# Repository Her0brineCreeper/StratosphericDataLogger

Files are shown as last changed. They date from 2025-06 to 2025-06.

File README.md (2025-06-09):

# StratosphericDataLogger
This repository contains the design and source code of the Stratospheric Data Logger developed by Bryan Hoxha during the European Project Semester 2025 at Politehnica Bucharest.
It was developed to log the measurements of a number of sensors onto a microSD card during a stratospheric balloon flight.
# Hardware
- ESP32 microcontroller (a FireBeetle 2 ESP32-E was used for this project)
- 2x BME280 for inside and outside the payload
- MS5611 pressure sensor (inside)
- SCD41 CO₂ sensor (inside)
- SI1145 light/UV sensor (outside)
- RCB-09T-01 GPS module (other GPS modules should work fine as well)
- SPI microSD card module
- custom-made PCB (made in KiCad v8) with modular design and two extra outputs (I²C) for additional sensors
- one of which was used for an MPU6050 accelerometer/gyroscope (inside)
# Software
- made in Arduino IDE
- logs sensor measurements to a CSV file and outputs them to Serial Monitor
- Sensors are hot pluggable during operation because their presence is checked during every measurement cycle.

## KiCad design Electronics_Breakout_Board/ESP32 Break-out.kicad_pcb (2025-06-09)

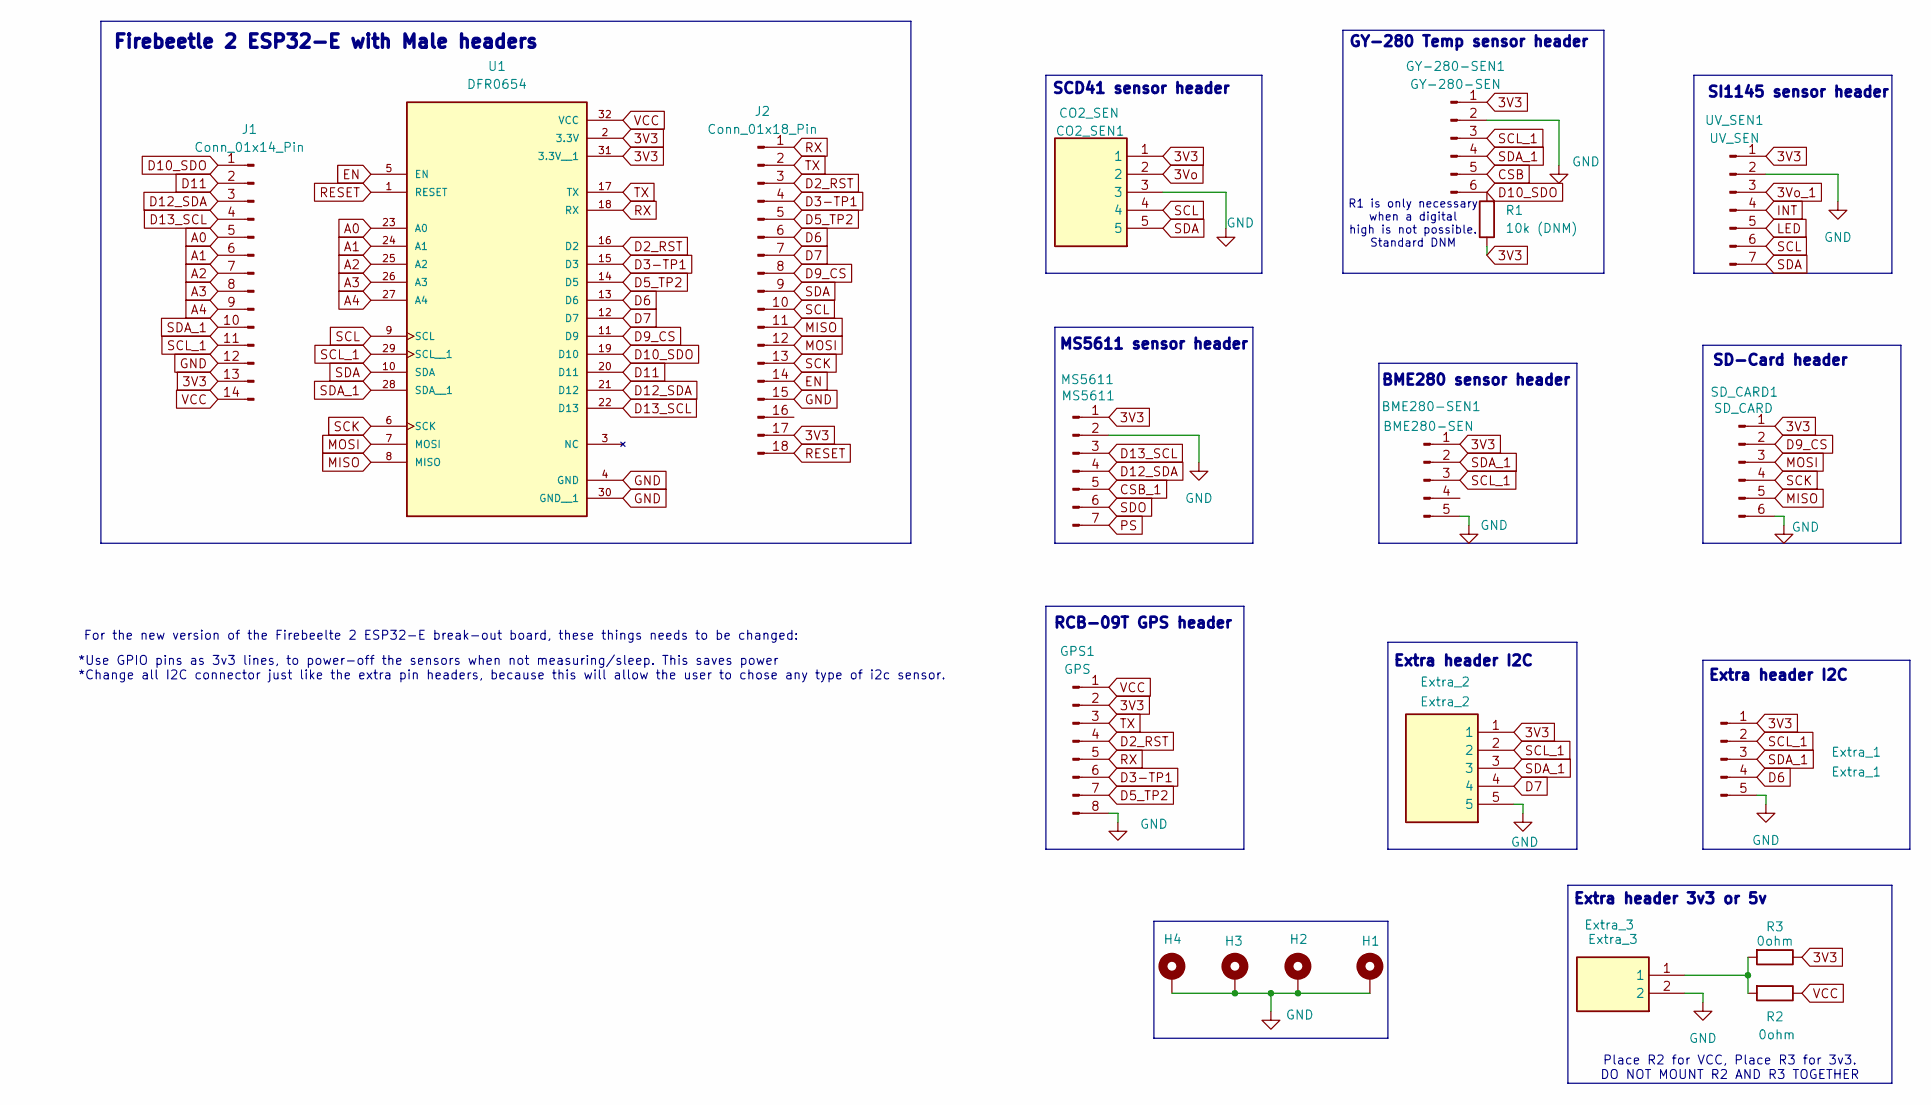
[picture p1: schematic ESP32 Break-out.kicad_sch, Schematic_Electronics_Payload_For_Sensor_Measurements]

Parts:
BME280-SEN1: BME280-SEN; 2200970571
CO2_SEN1: CO2_SEN; 2200970571; Manufacturer_Part_Number 220097-0571
Extra_1: Extra_1; 2200970571; Manufacturer_Part_Number 220097-0571
Extra_2: Extra_2; 2200970571; Manufacturer_Part_Number 220097-0571
Extra_3: Extra_3; 2200970271; Manufacturer_Part_Number 220097-0271; Mouser Part Number 538-220097-0271
GPS1: GPS; 2200970871
GY-280-SEN1: GY-280-SEN; 2200970671
H1, H2, H3, H4: MountingHole_Pad; MountingHole_2.2mm_M2_DIN965_Pad
J1: Conn_01x14_Pin; PinHeader_1x14_P2.54mm_Vertical
J2: Conn_01x18_Pin; PinHeader_1x18_P2.54mm_Vertical
MS5611: MS5611; CONN_2200970000-SD_07_MOL
R1: 10k (DNM); C_0805_2012Metric
R2, R3: 0ohm; C_0805_2012Metric
SD_CARD1: SD_CARD; 2200970671
U1: DFR0654; MODULE_DFR0654
UV_SEN1: UV_SEN; CONN_2200970000-SD_07_MOL

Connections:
3V3: BME280-SEN1.1, CO2_SEN1.1, Extra_1.1, Extra_2.1, GPS1.2, GY-280-SEN1.1, J1.13, J2.17, MS5611.1, R1.1, R3.1, SD_CARD1.1, U1.2 (3.3V), U1.31 (3.3V__1), UV_SEN1.1
3Vo: CO2_SEN1.2
3Vo_1: UV_SEN1.3
A0: J1.5, U1.23 (A0)
A1: J1.6, U1.24 (A1)
A2: J1.7, U1.25 (A2)
A3: J1.8, U1.26 (A3)
A4: J1.9, U1.27 (A4)
CSB: GY-280-SEN1.5
CSB_1: MS5611.5
D2_RST: GPS1.4, J2.3, U1.16 (D2)
D3-TP1: GPS1.6, J2.4, U1.15 (D3)
D5_TP2: GPS1.7, J2.5, U1.14 (D5)
D6: Extra_1.4, J2.6, U1.13 (D6)
D7: Extra_2.4, J2.7, U1.12 (D7)
D9_CS: J2.8, SD_CARD1.2, U1.11 (D9)
D10_SDO: GY-280-SEN1.6, J1.1, R1.2, U1.19 (D10)
D11: J1.2, U1.20 (D11)
D12_SDA: J1.3, MS5611.4, U1.21 (D12)
D13_SCL: J1.4, MS5611.3, U1.22 (D13)
EN: J2.14, U1.5 (EN)
GND: BME280-SEN1.5, CO2_SEN1.3, Extra_1.5, Extra_2.5, Extra_3.2, GPS1.8, GY-280-SEN1.2, H1.1, H2.1, H3.1, H4.1, J1.12, J2.15, MS5611.2, SD_CARD1.6, U1.4 (GND), U1.30 (GND__1), UV_SEN1.2
INT: UV_SEN1.4
LED: UV_SEN1.5
MISO: J2.11, SD_CARD1.5, U1.8 (MISO)
MOSI: J2.12, SD_CARD1.3, U1.7 (MOSI)
unnamed: Extra_3.1, R2.2, R3.2
PS: MS5611.7
RESET: J2.18, U1.1 (RESET)
RX: GPS1.5, J2.1, U1.18 (RX)
SCK: J2.13, SD_CARD1.4, U1.6 (SCK)
SCL: CO2_SEN1.4, J2.10, U1.9 (SCL), UV_SEN1.6
SCL_1: BME280-SEN1.3, Extra_1.2, Extra_2.2, GY-280-SEN1.3, J1.11, U1.29 (SCL__1)
SDA: CO2_SEN1.5, J2.9, U1.10 (SDA), UV_SEN1.7
SDA_1: BME280-SEN1.2, Extra_1.3, Extra_2.3, GY-280-SEN1.4, J1.10, U1.28 (SDA__1)
SDO: MS5611.6
TX: GPS1.3, J2.2, U1.17 (TX)
VCC: GPS1.1, J1.14, R2.1, U1.32 (VCC)

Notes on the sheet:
MS5611 sensor header
*Use GPIO pins as 3v3 lines, to power-off the sensors when not measuring/sleep. This saves power *Change all I2C connector just like the extra pin headers, because this will allow the user to chose any type of i2c sensor.
For the new version of the Firebeelte 2 ESP32-E break-out board, these things needs to be changed:
SCD41 sensor header
RCB-09T GPS header
SI1145 sensor header
GY-280 Temp sensor header
Extra header I2C
Firebeetle 2 ESP32-E with Male headers
BME280 sensor header
Extra header 3v3 or 5v
R1 is only necessary when a digital high is not possible. Standard DNM
SD-Card header
Place R2 for VCC, Place R3 for 3v3. DO NOT MOUNT R2 AND R3 TOGETHER

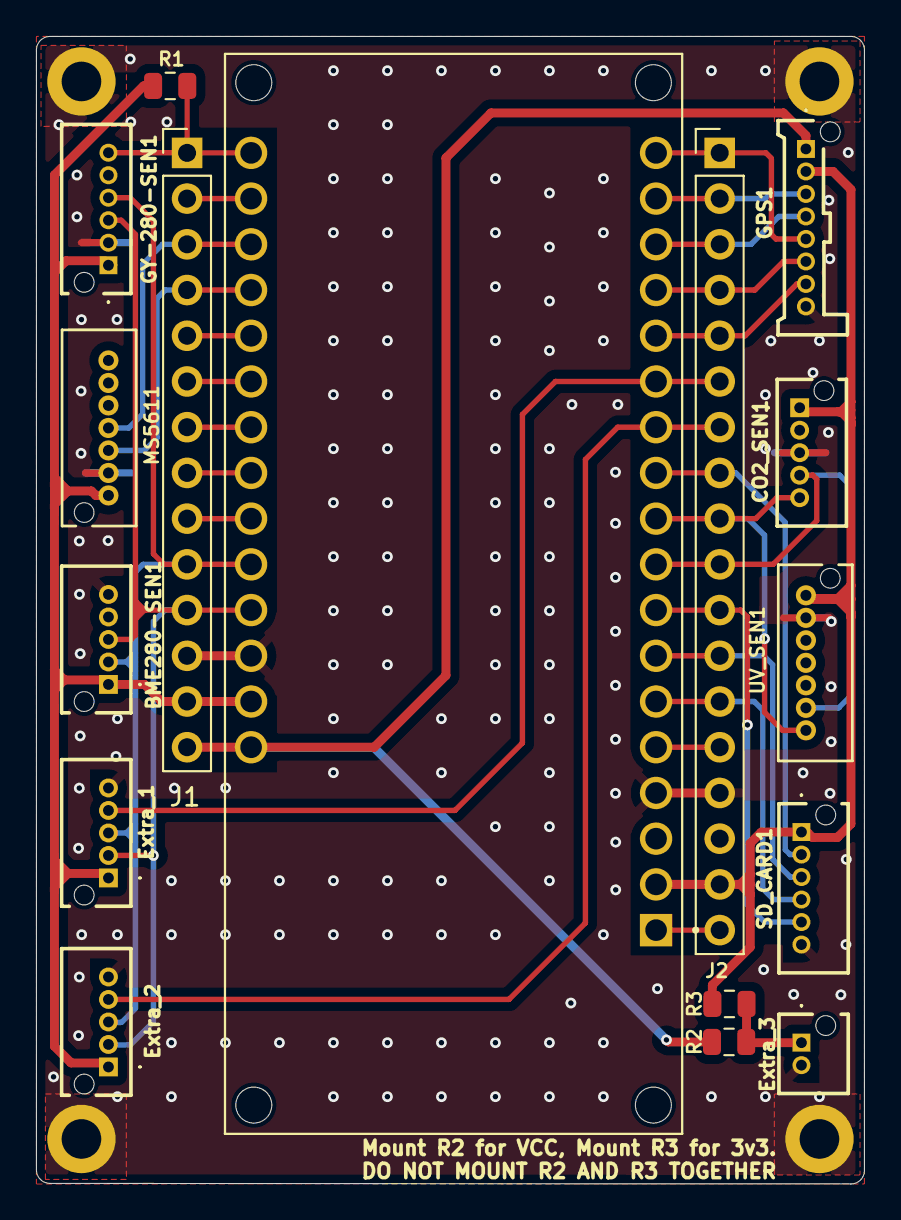
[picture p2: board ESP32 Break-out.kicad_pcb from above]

Board: 2 copper layers, 46.0 x 63.8 mm, 20 parts (0 on the bottom side), 30 nets.

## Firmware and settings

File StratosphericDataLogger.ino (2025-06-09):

#include <Wire.h>
#include "esp_sleep.h"
#include <SPI.h>
#include <SD.h>
#include <Adafruit_MPU6050.h>
#include <Adafruit_Sensor.h>
#include <Adafruit_BME280.h>
#include "Adafruit_SI1145.h"
#include <HardwareSerial.h>
#include <TinyGPSPlus.h>
#include <Arduino.h>
#include "SparkFun_SCD4x_Arduino_Library.h"
#include "MS5611.h"
#include <FastLED.h>

#define SEALEVELPRESSURE_HPA (1013.25)

//Define all I2C addreses
#define BME280_ADDR 0x76
#define GY280_ADDR 0x77
#define SI1145_ADDR 0x60
#define MPU6050_ADDR 0x68
#define SCD41_ADDR 0x62
#define MS5611_ADDR 0x77

//Define custom UART pins
#define GNSS_RX D6
#define GNSS_TX D7

//Pull-up to change addres to 0x77 for the GY-280
#define outputPin D10

//Define custom I2C pins
#define SDA_PIN D12  // Change as needed
#define SCL_PIN D11  // Change as needed

//Define SPI communication pins
#define SD_CS D9

//Define filename
#define FILENAME "/logdata.txt"

//Define for RGB LED
#define NUM_LEDS 1         //Number of RGB LED beads
#define DATA_PIN D8        //The pin for controlling RGB LED
#define LED_TYPE NEOPIXEL  //RGB LED strip type

CRGB leds[NUM_LEDS];  //Instantiate RGB LED

File dataFile;

TinyGPSPlus gps;
Adafruit_BME280 bme1;
Adafruit_BME280 bme2;
Adafruit_SI1145 uv = Adafruit_SI1145();
Adafruit_MPU6050 mpu;
SCD4x scd41;
MS5611 ms5611(0x77, &Wire1);

HardwareSerial GNSS(2);

bool bme1Present = false;
bool bme2Present = false;
bool uvPresent = false;
bool mpuPresent = false;
bool scd41Present = false;
bool ms5611Present = false;
bool sdPresent = false;

bool checkI2CDevice(TwoWire &bus, uint8_t address) {
  bus.beginTransmission(address);
  return (bus.endTransmission() == 0);
}

void blinkLED() {
  leds[0] = CRGB::HotPink;
  FastLED.setBrightness(40);
  FastLED.show();
  delay(500);
  leds[0] = CRGB::Black;
  FastLED.show();
  delay(500);
}

void SD_CheckLED(CRGB color) {
  leds[0] = CRGB::Black;
  FastLED.show();
  delay(100);
  leds[0] = color;
  FastLED.setBrightness(50);
  FastLED.show();
  delay(1000);
  leds[0] = CRGB::Black;
  FastLED.show();
  delay(100);
}

void setup() {
  Serial.begin(115200);

  pinMode(outputPin, OUTPUT);
  digitalWrite(outputPin, HIGH);

  Wire.begin();
  Wire1.begin(SDA_PIN, SCL_PIN);  //Second I2C buss

  FastLED.addLeds<LED_TYPE, DATA_PIN>(leds, NUM_LEDS);  //Initialize RGB LED
  leds[0] = CRGB::Black;
  FastLED.show();
  FastLED.clear(true);

  GNSS.begin(115200, SERIAL_8N1, GNSS_RX, GNSS_TX);
  Serial.println("GNSS module initialized.");

  if (checkI2CDevice(Wire, BME280_ADDR) && bme1.begin(BME280_ADDR)) {
    Serial.println("BME280 detected.");
    blinkLED();
    bme1Present = true;
  }

  if (checkI2CDevice(Wire, GY280_ADDR) && bme2.begin(GY280_ADDR)) {
    Serial.println("GY-280 detected.");
    blinkLED();
    bme2Present = true;
  }

  if (checkI2CDevice(Wire, SI1145_ADDR) && uv.begin()) {
    Serial.println("SI1145 detected.");
    blinkLED();
    uvPresent = true;
  }

  if (checkI2CDevice(Wire, MPU6050_ADDR) && mpu.begin()) {
    Serial.println("MPU6050 detected.");
    blinkLED();
    mpuPresent = true;
  }

  if (checkI2CDevice(Wire, SCD41_ADDR) && scd41.begin()) {
    Serial.println("SCD41 detected.");
    scd41.startPeriodicMeasurement();
    blinkLED();
    scd41Present = true;
  }

  if (checkI2CDevice(Wire1, MS5611_ADDR) && ms5611.begin()) {
    Serial.println("MS5611 detected.");
    blinkLED();
    ms5611Present = true;
  }

  SPI.begin(18, 19, 23, SD_CS);  // Set SPI pins: SCK, MISO, MOSI, CS
  if (!SD.begin(SD_CS)) {
    sdPresent = false;
    leds[0] = CRGB::Red;
    FastLED.setBrightness(40);
    FastLED.show();
    Serial.println("Card Mount Failed");
    delay(3000);
  } else {
    delay(100);
    sdPresent = true;
    leds[0] = CRGB::Green;  //LED shows green light
    FastLED.setBrightness(40);
    FastLED.show();
    Serial.println("Card mount works!");
    delay(3000);
  }

  // Try opening file for read first to check if it exists
  if (!SD.exists(FILENAME)) {
    Serial.println("File does not exist. Creating and writing header...");
    dataFile = SD.open(FILENAME, FILE_WRITE);
    if (dataFile) {
      dataFile.println("Time(ms),GPS_Date(DD/MM/YYYY),GPS_Time(HH:MM:SS),BME_T(C),BME_H(%),BME_P(hPa),GY_T(C),GY_H(%),GY_P(hPa),Vis,IR,UV,Ax,Ay,Az,Gx,Gy,Gz,MPU_T(C),CO2(ppm),SCD_T(C),SCD_H(%),MS_T(C),MS_P(hPa),Lat,Lon,Alt,Sats,HDOP");
      dataFile.flush();  // Force header to be written
      dataFile.close();
      Serial.println("Header written.");
    } else {
      Serial.println("Failed to create file. Disabling SD logging.");
      sdPresent = false;
    }
  }
}
void loop() {
  // Start CSV line with timestamp
  unsigned long timeStamp = millis();
  String csvLine = String(timeStamp);

  String gpsDate = ",,";
  if (gps.date.isValid() && gps.time.isValid()) {
    gpsDate = String(",") + String(gps.date.day()) + "/" + String(gps.date.month()) + "/" + String(gps.date.year());
    gpsDate += "," + String(gps.time.hour()) + ":" + String(gps.time.minute()) + ":" + String(gps.time.second());
  }
  csvLine += gpsDate;


  while (GNSS.available()) {
    gps.encode(GNSS.read());
  }

  Serial.println("-----------\n");

  // ---------- BME280 ----------
  Serial.println("Sensor BME280");
  if (checkI2CDevice(Wire, BME280_ADDR)) {
    if (!bme1Present && bme1.begin(BME280_ADDR)) {
      Serial.println("BME280 reconnected.");
      bme1Present = true;
    }
    if (bme1Present) {
      printBME280(bme1);
      csvLine += "," + String(bme1.readTemperature(), 2);
      csvLine += "," + String(bme1.readHumidity(), 2);
      csvLine += "," + String(bme1.readPressure() / 100.0F, 2);
    } else {
      csvLine += ",,,";
    }
  } else {
    if (bme1Present) Serial.println("BME280 disconnected!");
    bme1Present = false;
    Serial.println("Skipping BME280 readings... Not connected");
    csvLine += ",,,";
  }

  Serial.println("-----------\n");

  // ---------- GY-280 ----------
  Serial.println("Sensor GY-280");
  if (checkI2CDevice(Wire, GY280_ADDR)) {
    if (!bme2Present && bme2.begin(GY280_ADDR)) {
      Serial.println("GY-280 reconnected.");
      bme2Present = true;
    }
    if (bme2Present) {
      printBME280(bme2);
      csvLine += "," + String(bme2.readTemperature(), 2);
      csvLine += "," + String(bme2.readHumidity(), 2);
      csvLine += "," + String(bme2.readPressure() / 100.0F, 2);
    } else {
      csvLine += ",,,";
    }
  } else {
    if (bme2Present) Serial.println("GY-280 disconnected!");
    bme2Present = false;
    Serial.println("Skipping GY-280 readings... Not connected");
    csvLine += ",,,";
  }

  Serial.println("-----------\n");

  // ---------- SI1145 ----------
  Serial.println("Sensor SI1145");
  if (checkI2CDevice(Wire, SI1145_ADDR)) {
    if (!uvPresent && uv.begin()) {
      Serial.println("SI1145 reconnected.");
      uvPresent = true;
    }
    if (uvPresent) {
      printSI1145(uv);
      csvLine += "," + String(uv.readVisible());
      csvLine += "," + String(uv.readIR());
      csvLine += "," + String(uv.readUV() / 100.0, 2);
    } else {
      csvLine += ",,,";
    }
  } else {
    if (uvPresent) Serial.println("SI1145 disconnected!");
    uvPresent = false;
    Serial.println("Skipping SI1145 readings... Not connected");
    csvLine += ",,,";
  }

  Serial.println("-----------\n");

  // ---------- MPU6050 ----------
  Serial.println("Sensor MPU6050");
  if (checkI2CDevice(Wire, MPU6050_ADDR)) {
    if (!mpuPresent && mpu.begin()) {
      Serial.println("MPU6050 reconnected.");
      mpuPresent = true;
    }
    if (mpuPresent) {
      sensors_event_t a, g, temp;
      mpu.getEvent(&a, &g, &temp);
      printMPU6050(mpu);
      csvLine += "," + String(a.acceleration.x, 2);
      csvLine += "," + String(a.acceleration.y, 2);
      csvLine += "," + String(a.acceleration.z, 2);
      csvLine += "," + String(g.gyro.x, 2);
      csvLine += "," + String(g.gyro.y, 2);
      csvLine += "," + String(g.gyro.z, 2);
      csvLine += "," + String(temp.temperature, 2);
    } else {
      csvLine += ",,,,,,,";
    }
  } else {
    if (mpuPresent) Serial.println("MPU6050 disconnected!");
    mpuPresent = false;
    Serial.println("Skipping MPU6050 readings... Not connected");
    csvLine += ",,,,,,,";
  }

  Serial.println("-----------\n");

  // ---------- SCD41 ----------
  Serial.println("Sensor SCD41");
  if (checkI2CDevice(Wire, SCD41_ADDR)) {
    if (!scd41Present && scd41.begin()) {
      Serial.println("SCD41 reconnected.");
      scd41Present = true;
    }
    if (scd41Present && scd41.readMeasurement()) {
      printSCD41();
      csvLine += "," + String(scd41.getCO2());
      csvLine += "," + String(scd41.getTemperature(), 1);
      csvLine += "," + String(scd41.getHumidity(), 1);
    } else {
      csvLine += ",,,";
    }
  } else {
    if (scd41Present) Serial.println("SCD41 disconnected!");
    scd41Present = false;
    Serial.println("Skipping SCD41 readings... Not connected");
    csvLine += ",,,";
  }

  Serial.println("-----------\n");

  // ---------- MS5611 ----------
  Serial.println("Sensor MS5611");
  if (checkI2CDevice(Wire1, MS5611_ADDR)) {
    if (!ms5611Present && ms5611.begin()) {
      Serial.println("MS5611 reconnected.");
      ms5611Present = true;
    }
    if (ms5611Present) {
      ms5611.read();
      printMS5611();
      csvLine += "," + String(ms5611.getTemperature(), 2);
      csvLine += "," + String(ms5611.getPressure(), 2);
    } else {
      csvLine += ",,";
    }
  } else {
    if (ms5611Present) Serial.println("MS5611 disconnected!");
    ms5611Present = false;
    Serial.println("Skipping MS5611 readings... Not connected");
    csvLine += ",,";
  }

  Serial.println("-----------\n");

  // ---------- GNSS ----------
  Serial.println("Sensor GNSS");
  printGPS();
  if (gps.location.isValid()) {
    csvLine += "," + String(gps.location.lat(), 6);
    csvLine += "," + String(gps.location.lng(), 6);
    csvLine += "," + String(gps.altitude.meters(), 2);
    csvLine += "," + String(gps.satellites.value());
    csvLine += "," + String(gps.hdop.hdop(), 1);
  } else {
    csvLine += ",,,,";
  }

  Serial.println("-----------\n");

  if (!sdPresent) {
    Serial.println("SD-Card not detected... No Data Logging");
    SD_CheckLED(CRGB::Red);
  }

  Serial.println("-----------\n");

  // Write the final line to the SD card
  logToSD(csvLine);

  // Set up a timer to wake us after 10 seconds
  esp_sleep_enable_timer_wakeup(10 * 1000000ULL - (micros() - timeStamp*1000));  // 10 seconds in microseconds

  Serial.println("Entering light sleep mode...");
  Serial.flush();  // Ensure serial output is flushed

  // Enter light sleep
  esp_light_sleep_start();

  Serial.println("Woke up from light sleep.");
}

void printBME280(Adafruit_BME280 &sensor) {
  Serial.print("Temp: ");
  Serial.print(sensor.readTemperature());
  Serial.println(" °C");

  Serial.print("Pressure: ");
  Serial.print(sensor.readPressure() / 100.0F);
  Serial.println(" hPa");

  Serial.print("Humidity: ");
  Serial.print(sensor.readHumidity());
  Serial.println(" %");
}

void printSI1145(Adafruit_SI1145 &sensor) {
  Serial.print("Vis: ");
  Serial.println(sensor.readVisible());

  Serial.print("IR: ");
  Serial.println(sensor.readIR());

  float UVindex = sensor.readUV();
  UVindex /= 100.0;
  Serial.print("UV: ");
  Serial.println(UVindex);
}

void printMPU6050(Adafruit_MPU6050 &sensor) {
  sensors_event_t a, g, temp;
  mpu.getEvent(&a, &g, &temp);

  Serial.print("Acceleration X: ");
  Serial.print(a.acceleration.x);
  Serial.print(", Y: ");
  Serial.print(a.acceleration.y);
  Serial.print(", Z: ");
  Serial.print(a.acceleration.z);
  Serial.println(" m/s^2");

  Serial.print("Rotation X: ");
  Serial.print(g.gyro.x);
  Serial.print(", Y: ");
  Serial.print(g.gyro.y);
  Serial.print(", Z: ");
  Serial.print(g.gyro.z);
  Serial.println(" rad/s");

  Serial.print("Temperature: ");
  Serial.print(temp.temperature);
  Serial.println(" °C");
}

void printSCD41() {
  Serial.println();
  Serial.print(F("CO2(ppm):"));
  Serial.print(scd41.getCO2());
  Serial.print(F("\tTemperature(C):"));
  Serial.print(scd41.getTemperature(), 1);
  Serial.print(F("\tHumidity(%RH):"));
  Serial.print(scd41.getHumidity(), 1);
  Serial.println();
}

void printMS5611() {
  // Read data from MS5611
  //ms5611.read();  // Note: no error checking here
  Serial.print("T:\t");
  Serial.print(ms5611.getTemperature(), 2);
  Serial.print("\tP:\t");
  Serial.print(ms5611.getPressure(), 2);
  Serial.println();
}

void printGPS() {
  if (gps.location.isUpdated()) {
    Serial.print("Latitude: ");
    Serial.println(gps.location.lat(), 6);
    Serial.print("Longitude: ");
    Serial.println(gps.location.lng(), 6);
    Serial.print("Altitude: ");
    Serial.print(gps.altitude.meters());
    Serial.println(" m");
    Serial.print("Satellites: ");
    Serial.println(gps.satellites.value());
    Serial.print("HDOP: ");
    Serial.println(gps.hdop.hdop());
    Serial.print("Time (UTC): ");
    if (gps.time.isValid()) {
      Serial.printf("%02d:%02d:%02d\n", gps.time.hour(), gps.time.minute(), gps.time.second());
    } else {
      Serial.println("Invalid");
    }
    Serial.print("Date: ");
    if (gps.date.isValid()) {
      Serial.printf("%02d/%02d/%d\n", gps.date.day(), gps.date.month(), gps.date.year());
      leds[0] = CRGB::Green;
      FastLED.setBrightness(40);
      FastLED.show();
      delay(1000);
      leds[0] = CRGB::Black;
    } else {
      Serial.println("Invalid");
    }
  } else {
    Serial.println("Waiting for GPS fix...");
    leds[0] = CRGB::Blue;
    FastLED.setBrightness(40);
    FastLED.show();
    delay(1000);
    leds[0] = CRGB::Black;
    FastLED.show();
  }
}

void logToSD(String csvLine) {
  if (!sdPresent) return;

  dataFile = SD.open(FILENAME, FILE_APPEND);
  if (dataFile) {
    dataFile.println(csvLine);
    dataFile.flush();  // Force writing to card
    dataFile.close();  // Ensure data is saved
    Serial.println("Data written to SD.");
    delay(200);
    SD_CheckLED(CRGB::Green);
  } else {
    Serial.println("Failed to open file for writing. SD logging disabled.");
    sdPresent = false;
  }
}
